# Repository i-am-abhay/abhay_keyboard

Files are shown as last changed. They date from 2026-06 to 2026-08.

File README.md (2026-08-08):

<div align="center">

<br><br><br>

Screenshot 2026-07-06 at 4 13 24 PM

<br><br><br><br><br><br>

<div align="left">

### About the Project

This project is a custom mechanical keyboard that I designed and built from scratch. It features a custom PCB, mechanical switches, RGB lighting, and a 128×32 OLED display. The keyboard runs custom firmware that handles the key matrix, USB input, OLED, and lighting.

I designed the PCB and case myself, then assembled the hardware and wrote the firmware to bring everything together. The goal was to make a keyboard that I could actually use every day while having complete control over both the hardware and software.

<br><br>

### Why I Built It

I wanted to see if I could build a full-size keyboard completely from scratch instead of buying one. I had already worked on smaller hardware projects, so this felt like a good way to take things further and build something I would actually use every day.

It also gave me a chance to work on things I hadn't done at this scale before, like designing a large PCB, routing a keyboard matrix, writing firmware, and making a case that all fit together properly. In the end, I wanted to turn something I use every day into a project I could design myself.

<br><br><br><br><br><br>

<div align="center">

### Sponsored By

<br><br>

Hack Club

<br><br><br><br>

pcbway-logo-png_seeklogo-615986

<br><br><br>

## PCBWay Sponsorship

<div align="left">
  
A massive thank you to **[PCBWay](https://www.pcbway.com/)** for sponsoring the manufacturing of the **Velune Keyboard PCB** and being a part of this journey!

When I first started this project, it was just an idea sitting in my head, the goal of designing my own mechanical keyboard completely from scratch. I wanted to experience every part of the process: drawing the schematic, designing the PCB, writing the firmware, creating the hardware, and eventually holding something I built myself.

After countless hours in KiCad, debugging, redesigning, and improving the design, the project reached a point where it was ready to leave my computer and become a real physical device. That is where PCBWay made a huge difference.

With PCBWay's support, my PCB design was able to become a real prototype that I can assemble, test, and continue improving. Having a professionally manufactured board for something I designed myself is an incredible milestone and a reminder of why I love building hardware.

This sponsorship is not just about getting PCBs manufactured. It is about making it possible for creators like me to learn through building and share that experience with others. I will be documenting the entire process, from PCB fabrication and assembly to testing the final keyboard, so others can follow along and hopefully be inspired to start their own projects.

### Learn More About PCBWay!

* 🌐 **PCB Manufacturing:** [PCBWay](https://www.pcbway.com/)
* 🛠️ **PCBWay Community:** [PCBWay Project Community](https://www.pcbway.com/project/)

I am genuinely thankful to the PCBWay team for supporting student creators and giving me the opportunity to turn an idea into a real piece of hardware. Your support helped make **abhay_keyboard** something more than just a design file. It became a project I can build, share, and continue improving.

Thank you, PCBWay, for believing in this project and helping me bring it to life.

</div>

<br><br><br><br>

<div align="center">

### Bill of Materials

<br>

<div align="center">

| Qty | Component | Cost |
| :-: | --- | --- |
| 78x | [SOD-123 Diodes](https://www.aliexpress.com/item/3256805388348871.html) | $1.53  |
| 79x | [1206 Capacitors (104K 50V)](https://www.aliexpress.com/item/3256807177349573.html) | $1.46  |
|  1x | [74AHCT125 Bus Buffer](https://www.aliexpress.com/item/3256807066238250.html) | $1.66  |
| 78x | [SK6812 MINI-E RGB LEDs](https://www.aliexpress.us/item/3256805007401420.html) | $6.48  |
|  1x | [SSD1306 128×32 OLED Display](https://www.aliexpress.com/item/2251832623890853.html) | $1.52  |
|  4x | [6mm M3 Machine Screws](https://www.aliexpress.com/item/2255800784679048.html) | $2.45  |
| 78x | [Mechanical Switches](https://www.aliexpress.com/item/3256808352947766.html) | $22.79 |
|  1x | [Raspberry Pi Pico RP2040](https://www.aliexpress.com/item/3256806652932348.html) | $7.28  |
|  1x | [Keycap Set](https://www.aliexpress.com/item/3256809986262551.html) | $15.51 |
|  1x | [Keyboard Stabilizer Set](https://www.aliexpress.com/item/3256801595153884.html) | $3.71  |
|  4x | [M2.5 Self-Tapping Screws](https://www.aliexpress.com/item/2255800784679048.html) | $2.61  |
|  4x | [M3 Heat-Set Inserts](https://www.aliexpress.com/item/3256808480358197.html) | $2.15  |
|  1x | [GPIO Header Set (Raspberry Pi Pico)](https://www.aliexpress.com/item/3256808268220851.html) | $2.19  |
|  1x | [Custom PCB  (**SPONSORED BY PCBWAY**)  ](https://www.pcbway.com/) | $0.00  |
|  1x | 3D Printed Case (Printing Legion) | $0.00  | 

<br>

**Parts Subtotal:** $76.48 

**Fees  |  Tax:** $6.34

**PCBWAY Shipping:** $60

**Grand Total:** $142.82

<br><br><br><br><br>

### PCB Schematic

<br>

Screenshot 2026-06-18 at 11 05 58 AM

<br><br>

### PCB Layout

<br>

<div align="center">

**Top Layer**

<br>

Screenshot 2026-06-18 at 5 12 39 PM

<br><br>

**Bottom Layer**

<br>

Screenshot 2026-06-18 at 5 12 57 PM

<br><br>

**3D View**

<br>

Screenshot 2026-06-18 at 5 15 27 PM

<br><br>

Screenshot 2026-06-18 at 5 15 45 PM

</div>

<br><br>

### Case Design

<br>

<div align="center">

**Top Case**

<br>

Screenshot 2026-06-18 at 5 12 09 PM

<br><br>

**Plate**

<br>

Screenshot 2026-06-18 at 5 11 52 PM

<br><br>

**Bottom Case**

<br>

Screenshot 2026-06-18 at 5 12 13 PM

</div>

<br><br>

### Final Assembly

<br>

<div align="center">

Screenshot 2026-06-18 at 5 18 41 PM

<br><br>

<div align="center">

*Designed and Built by Abhay P.*

</div>

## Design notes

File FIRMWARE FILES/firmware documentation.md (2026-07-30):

# Mechanical Keyboard Firmware Documentation

## Overview

This firmware runs my custom mechanical keyboard using a custom keyboard controller and CircuitPython firmware.

It handles:

- Full keyboard key input
- SSD1306 128×32 OLED display
- Per-key NeoPixel RGB LED lighting
- Full key matrix scanning
- USB keyboard input

Everything works together to handle typing input, visual feedback, and keyboard controls.

---

## Hardware

### Microcontroller

- Custom keyboard controller
- CircuitPython-compatible MCU

### Display

- SSD1306 OLED (128×32, I2C)
- Address: `0x3C`
- Framebuffer-based display driver

### Input

- Custom keyboard layout
- Full keyboard matrix
- Mechanical MX-style switches
- Diode-protected matrix

### Output

- Individual RGB LEDs assigned to each key
- Custom lighting effects and animations

---

## Pin Mapping

### Key Matrix

- Rows: Configured based on keyboard PCB layout
- Columns: Configured based on keyboard PCB layout
- Diode orientation: `COL2ROW`

### OLED (I2C)

- SDA: Configured GPIO pin
- SCL: Configured GPIO pin
- I2C Speed: 400 kHz

### RGB LEDs

- Data: Configured GPIO pin
- LED Count: Configured based on keyboard PCB

---

## Key System

Each key has:

- A physical switch position
- A keyboard keycode
- An RGB lighting position
- A matrix row and column location
- Optional custom behavior

### Current key actions

- Standard keyboard input
- Function keys
- Navigation keys
- Arrow keys
- Number pad support
- Modifier keys
- Media controls

---

## Key Press Behavior

When a key is pressed:

1. The matrix scanner detects the switch press.
2. The key debounce system confirms the input.
3. The keyboard sends the matching USB HID keycode.
4. The OLED updates with keyboard status.
5. The matching key LED animation starts.

When the key is released:

- The key state is cleared.
- The HID release signal is sent.
- The LED animation returns to the idle state.

---

## OLED System

The OLED uses a framebuffer-based driver.

### Features

- Text rendering
- Keyboard status display
- Layer information
- Animation support
- Direct I2C updates

---

## OLED Animation States

### Idle

- Shows the current time in `HH:MM`
- Shows keyboard status below
- Slightly moves the display content to prevent static appearance

### Key Press

- Displays the pressed key name.
- Shows keyboard activity feedback.
- Updates only when the screen state changes.

### Hold

- The key information remains displayed briefly.

### Fade Out

- The display clears with a smooth wipe animation.
- The OLED returns to the idle screen.

---

## LED System

The LED system controls all keyboard RGB LEDs.

### Behavior

- LEDs remain in the selected idle mode.
- Pressing a key starts a lighting animation.
- Each key can have its own RGB color.

### On Key Press

- The pressed key LED activates.
- Lighting effects spread across the keyboard.
- The selected key color is displayed.

### On Key Release

- LEDs return to the idle lighting state.
- Effects clear smoothly.

### How it Works

- The animation runs inside the keyboard main loop.
- It uses timed updates instead of blocking delays.
- Key scanning continues while effects are running.

---

## LED Animation Engine

The LEDs use a time-based animation system.

### Press Animation

- The pressed key lights first.
- The effect expands across nearby LEDs.
- Each LED uses its assigned color.

### Release Animation

- The effect fades away.
- LEDs return to their default state.

### Timing

- Animation frames update using timed intervals.
- No blocking delays are used.

---

## Keyboard Matrix

The keyboard uses a row and column scanning system.

### How it Works

- The firmware activates one row at a time.
- Column inputs are checked for switch presses.
- The pressed switch location is converted into a keycode.
- The HID report is sent over USB.

### Features

- Debouncing
- Multiple key support
- Modifier key handling
- Full keyboard compatibility

---

## USB HID System

The keyboard communicates as a standard USB keyboard device.

### Features

- Plug-and-play support
- Standard keyboard shortcuts
- Modifier support
- Media key support

---

## Performance

### OLED

- The display only updates when required.
- Animations control when each frame is drawn.

### LEDs

- LED animations run inside the keyboard scan loop.
- They do not interrupt typing.
- Updates happen asynchronously.

### Input

- Matrix scanning runs continuously.
- Key presses are detected with low latency.
- Multiple keys can be pressed simultaneously.

---

## System Flow

1. A key is pressed.
2. The matrix scanner detects the switch.
3. The firmware processes the key event.
4. The USB HID report is sent.
5. The OLED shows keyboard feedback.
6. The RGB LED animation starts.
7. The keyboard returns to the idle state.

---

## Summary

This firmware brings the entire keyboard system together.

It includes:

- Full keyboard support
- Custom matrix scanning
- OLED visual feedback
- RGB lighting effects
- USB HID keyboard output

Everything runs together so the input system, display, lighting, and keyboard controls stay synchronized.

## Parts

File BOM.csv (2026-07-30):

Designator | Qty | Part Number | Package
C79,C61,C15,C1,C16,C76,C30,C54,C37,C67,C24,C66,C69,C27,C65,C11,C78,C68,C64,C13,C14,C62,C47,C71,C35,C4,C74,C5,C60,C9,C21,C45,C19,C25,C59,C17,C28,C8,C73,C56,C34,C50,C75,C22,C2,C29,C55,C46,C52,C20,C39,C44,C6,C33,C12,C7,C58,C38,C32,C36,C53,C43,C49,C42,C51,C70,C3,C77,C18,C41,C26,C57,C23,C40,C63,C48,C10,C72,C31 | 79 | 100nF | C_1206_3216Metric_Pad1.33x1.80mm_HandSolder
R1 | 1 | 330R | R_0805_2012Metric_Pad1.20x1.40mm_HandSolder
U2 | 1 | 74AHCT125 | SOIC-14_3.9x8.7mm_P1.27mm
D73,D25,D44,D31,D72,D66,D29,D37,D57,D63,D48,D67,D27,D70,D1,D49,D41,D64,D52,D74,D38,D23,D76,D60,D33,D16,D77,D46,D61,D47,D43,D15,D11,D34,D65,D51,D62,D14,D59,D56,D19,D40,D3,D32,D69,D10,D39,D13,D53,D6,D58,D45,D7,D54,D42,D36,D24,D35,D9,D22,D17,D8,D21,D18,D26,D28,D30,D75,D78,D55,D4,D50,D12,D68,D71,D20,D2,D5 | 78 | D | D_SOD-123
U1 | 1 | ER_OLEDM0.91_1x-I2C | ER_OLEDM0.91_1x-I2C
LED18,LED23,LED22,LED29,LED52,LED46,LED74,LED17,LED43,LED21,LED3,LED1,LED28,LED63,LED51,LED53,LED20,LED78,LED38,LED7,LED54,LED62,LED12,LED45,LED37,LED70,LED48,LED64,LED16,LED11,LED68,LED26,LED72,LED66,LED8,LED41,LED65,LED59,LED58,LED47,LED15,LED14,LED40,LED75,LED27,LED10,LED56,LED39,LED55,LED50,LED57,LED31,LED42,LED76,LED24,LED34,LED35,LED19,LED71,LED61,LED5,LED9,LED77,LED60,LED67,LED73,LED36,LED13,LED32,LED6,LED69,LED4,LED30,LED49,LED44,LED25,LED33,LED2 | 78 | MX_SK6812MINI-E | LED_MX_6028R
H1,H3,H2,H4 | 4 | MountingHole | MountingHole_3.2mm_M3
A1 | 1 | SC0918 | RaspberryPi_Pico_Common_THT
SW16,SW49,SW38,SW76,SW10,SW32,SW45,SW21,SW18,SW65,SW14,SW30,SW31,SW17,SW24,SW9,SW58,SW56,SW37,SW25,SW6,SW8,SW22,SW62,SW57,SW34,SW1,SW36,SW64,SW44,SW26,SW59,SW4,SW47,SW43,SW52,SW7,SW53,SW19,SW46,SW20,SW12,SW13,SW15,SW63,SW3,SW29,SW60,SW50,SW78,SW39,SW33,SW2,SW77,SW5,SW40,SW61,SW35,SW11,SW48,SW51,SW23 | 62 | SW_Push | SW_Cherry_MX_1.00u_PCB
SW69,SW75,SW67,SW72,SW70,SW73,SW74,SW68 | 8 | SW_Push | SW_Cherry_MX_1.25u_PCB
SW41,SW28 | 2 | SW_Push | SW_Cherry_MX_1.50u_PCB
SW42 | 1 | SW_Push | SW_Cherry_MX_1.75u_PCB
SW27 | 1 | SW_Push | SW_Cherry_MX_2.00u_PCB
SW54,SW55 | 2 | SW_Push | SW_Cherry_MX_2.25u_PCB
SW66 | 1 | SW_Push | SW_Cherry_MX_2.75u_PCB
SW71 | 1 | SW_Push | SW_Cherry_MX_6.25u_PCB

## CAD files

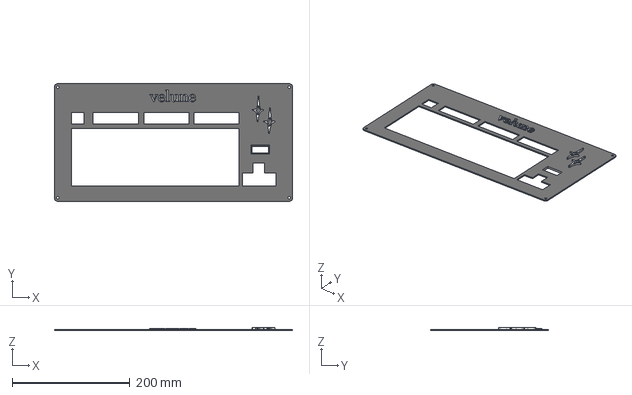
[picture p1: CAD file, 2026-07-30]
CAD FILES/KEYBOARD TOP CASE.step
405.0 x 200.0 x 5.00 mm

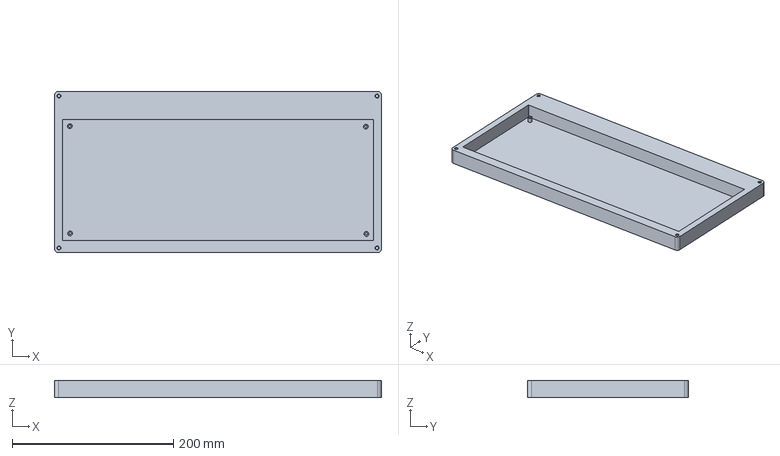
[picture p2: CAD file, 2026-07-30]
CAD FILES/KEYBOARD BOTTOM CASE.step
405.1 x 200.0 x 21.5 mm

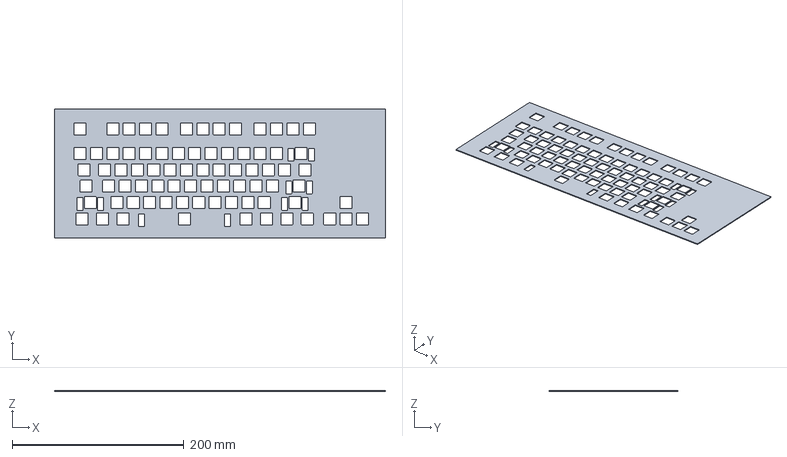
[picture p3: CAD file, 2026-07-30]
CAD FILES/PRODUCTION FOLDER/KEYBOARD PLATE.step
385.1 x 150.0 x 1.00 mm

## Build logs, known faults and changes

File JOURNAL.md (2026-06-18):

# 1. Keyboard Layout Planning

> ⏱️ **Time Logged:** 2 Hours

Before starting the electrical design, I spent time deciding on the overall layout of the keyboard. I chose a 75% layout because it balances functionality and desk space well. One challenge was fitting all 75 keys while maintaining comfortable spacing and room for the OLED display. I experimented with several arrangements before settling on the final design. This planning stage helped prevent larger issues later in the project and gave me a clearer idea of how all the components would fit together.

---

# 2. Schematic Design

> ⏱️ **Time Logged:** 4 Hours

I worked on creating the schematic for the keyboard. Compared to smaller projects I had done previously, this design was significantly more complicated because it included 75 switches, a Raspberry Pi Pico, an OLED display, and RGB underglow LEDs.

One challenge I encountered was organizing the keyboard matrix and ensuring every switch was connected correctly. During the design process I ran into several ERC errors caused by missing connections and incorrect net assignments. Rather than trying random fixes, I systematically reviewed each section of the schematic and traced every issue back to its source. After multiple revisions, I was able to eliminate all errors and complete a schematic that was both functional and organized.

---

# 3. PCB Layout & Routing

> ⏱️ **Time Logged:** 6 Hours

I worked on laying out and routing the PCB for the keyboard. This was by far the most time-consuming portion of the project.

With 75 switches, RGB LEDs, the OLED display, and supporting circuitry, routing quickly became challenging due to the large number of connections and limited space available. My initial placement resulted in several congested areas where routing became difficult. To solve this, I repositioned components multiple times and rerouted large portions of the board to improve trace organization.

I also had to carefully consider mounting hole placement and mechanical clearances to ensure traces would not be damaged during assembly. This stage taught me the importance of balancing electrical requirements with mechanical constraints. Overall, I am very happy with how compact and organized the final PCB turned out.

---

# 4. Plate Design

> ⏱️ **Time Logged:** 2 Hours

I designed the keyboard plate that supports all 75 switches. While it seemed straightforward at first, ensuring that every switch cutout was aligned correctly required careful attention to detail.

I spent time verifying measurements against both the PCB and key layout to ensure proper fitment. Since even small alignment errors can affect the assembly process, I double-checked all dimensions before finalizing the design.

---

# 5. Top Case Design

> ⏱️ **Time Logged:** 2 Hours

I created the top case for the keyboard. The primary challenge was integrating the switch openings, OLED display opening, and overall aesthetics while maintaining compatibility with the plate and PCB.

I made several adjustments to dimensions and clearances to ensure components would fit comfortably without interfering with one another. The final design provides support while maintaining a clean appearance.

---

# 6. Bottom Case Design

> ⏱️ **Time Logged:** 2 Hours

I created the bottom case that houses the PCB and internal electronics. Although the design itself was relatively simple, determining the correct dimensions required careful measurement.

I had to account for the thickness of the PCB, standoffs, mounting hardware, and tolerances associated with 3D printing. To reduce the risk of assembly issues, I added additional clearance in several locations where the fit would otherwise have been too tight.

---

# 7. Assembly Creation & Verification

> ⏱️ **Time Logged:** 1.5 Hours

I created a complete assembly model of the keyboard to verify that all components fit together correctly.

During this stage I discovered a few minor alignment issues that were not obvious when viewing individual parts. Being able to identify and correct these problems before manufacturing saved both time and potential cost. The assembly also allowed me to visualize the finished product and confirm that all dimensions were correct.

---

# 8. Firmware Development

> ⏱️ **Time Logged:** 2.5 Hours

I developed the firmware for the keyboard. Since I already had experience with Python, learning the basic structure of the firmware was not difficult. However, configuring the keyboard matrix, OLED display functionality, and RGB lighting required learning several new concepts.

I spent time reading documentation and experimenting with test configurations before implementing the final design. While there was a learning curve at first, I gained a much better understanding of how firmware interacts with hardware systems.

---

# 9. Parts Sourcing

> ⏱️ **Time Logged:** 2 Hours

I sourced all of the components required for the keyboard, including switches, keycaps, LEDs, the Raspberry Pi Pico, display, and assembly hardware.

I originally expected this process to be quick, but I quickly discovered that balancing cost, quality, and availability was more difficult than anticipated. Several components were either out of stock or significantly more expensive than expected. After comparing multiple suppliers and alternatives, I finalized a bill of materials that met both performance and budget requirements.

---

# 10. GitHub Repository & Documentation

> ⏱️ **Time Logged:** 1 Hour

I organized all project files and uploaded them to my GitHub repository. I also created documentation describing the project, design process, and manufacturing files.

Although documentation was one of the final steps, I believe it is an important part of any engineering project because it allows others to understand, reproduce, and improve upon the design in the future.

---

# Total Project Statistics

| Category | Time Logged |
| --- | ---: |
| Keyboard Layout Planning | 2 hrs |
| Schematic Design | 4 hrs |
| PCB Layout & Routing | 6 hrs |
| Plate Design | 2 hrs |
| Top Case Design | 2 hrs |
| Bottom Case Design | 2 hrs |
| Assembly Creation & Verification | 1.5 hrs |
| Firmware Development | 2.5 hrs |
| Parts Sourcing | 2 hrs |
| GitHub & Documentation | 1 hr |
| **Total Time** |  **25 hrs** |

---

# Reflection

I am immensely grateful for the opportunity to design and develop a custom keyboard from the ground up. I started this project because I wanted to create something that combined electrical engineering, mechanical design, and software development into a single product that I could personally use.

One of the biggest lessons I learned was that engineering is an iterative process. Whether I was fixing ERC errors, rerouting traces on the PCB, adjusting mechanical tolerances, or learning how to configure firmware features, very few parts of the project worked perfectly on the first attempt. Each challenge required research, experimentation, and multiple revisions before reaching a satisfactory solution.

Throughout the project I became more comfortable using professional design tools and working through technical problems independently. I also gained a deeper understanding of how electrical, mechanical, and software systems interact within a complete product. Most importantly, I was able to transform an initial idea into a fully designed keyboard that I am genuinely proud of. The experience and skills gained throughout this project will be valuable in future engineering projects and have strengthened my interest in hardware design.

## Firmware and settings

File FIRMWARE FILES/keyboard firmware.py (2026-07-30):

# code.py
# ANSI 104 Keyboard Placeholder
# Matrix + OLED + RGB LEDs

import time
import board
import busio
import displayio
import terminalio

from digitalio import DigitalInOut, Direction, Pull
import neopixel

import adafruit_displayio_ssd1306
from adafruit_display_text import label


# ==================================================
# OLED DISPLAY
# ==================================================

displayio.release_displays()

# Change pins if needed
i2c = busio.I2C(
    board.D5,   # SCL
    board.D4,   # SDA
    frequency=400000
)

display_bus = displayio.I2CDisplay(
    i2c,
    device_address=0x3C
)

display = adafruit_displayio_ssd1306.SSD1306(
    display_bus,
    width=128,
    height=32
)

screen = displayio.Group()

text = label.Label(
    terminalio.FONT,
    text="ANSI 104 Keyboard",
    x=0,
    y=8
)

screen.append(text)

display.root_group = screen


# ==================================================
# RGB LEDS
# ==================================================

# Change pin and count
LED_PIN = board.D10
LED_COUNT = 104

pixels = neopixel.NeoPixel(
    LED_PIN,
    LED_COUNT,
    brightness=0.2,
    auto_write=True
)

# Startup placeholder lighting
for i in range(LED_COUNT):
    pixels[i] = (20, 20, 20)

time.sleep(1)

pixels.fill((0, 0, 0))


# ==================================================
# ANSI 104 KEYMAP PLACEHOLDER
# ==================================================

KEYMAP = [

    # Function row
    [
        "ESC",
        "F1","F2","F3","F4",
        "F5","F6","F7","F8",
        "F9","F10","F11","F12"
    ],

    # Number row
    [
        "`","1","2","3","4",
        "5","6","7","8",
        "9","0","-","=",
        "BACKSPACE"
    ],

    # Q row
    [
        "TAB",
        "Q","W","E","R","T",
        "Y","U","I","O","P",
        "[","]","\\"
    ],

    # Home row
    [
        "CAPS",
        "A","S","D","F","G",
        "H","J","K","L",
        ";","'",
        "ENTER"
    ],

    # Bottom row
    [
        "SHIFT_L",
        "Z","X","C","V","B",
        "N","M",
        ",",".","/",
        "SHIFT_R"
    ],

    # Space row
    [
        "CTRL_L",
        "WIN_L",
        "ALT_L",
        "SPACE",
        "ALT_R",
        "FN",
        "CTRL_R"
    ],

    # Navigation
    [
        "INSERT",
        "HOME",
        "PAGE_UP",
        "DELETE",
        "END",
        "PAGE_DOWN"
    ],

    # Arrows
    [
        "UP",
        "LEFT",
        "DOWN",
        "RIGHT"
    ],

    # Numpad
    [
        "NUM_LOCK",
        "NUM/",
        "NUM*",
        "NUM-",
        "NUM7",
        "NUM8",
        "NUM9",
        "NUM+",
        "NUM4",
        "NUM5",
        "NUM6",
        "NUM1",
        "NUM2",
        "NUM3",
        "NUM_ENTER",
        "NUM0",
        "NUM."
    ]
]


# ==================================================
# MATRIX PLACEHOLDER
# ==================================================

ROWS = []
COLS = []


def scan_keyboard():
    """
    Add matrix scanning here:
    - set row pins
    - read columns
    - send HID reports
    """
    pass


# ==================================================
# MAIN LOOP
# ==================================================

while True:

    scan_keyboard()

    # OLED heartbeat placeholder
    text.text = "ANSI 104 Keyboard"

    time.sleep(0.01)

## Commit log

2026-07-30 Rename Wireless Keyboard.kicad_pcb to PCB FILES/Wireless Keyboard.kicad_pcb
    [Wireless Keyboard.kicad_pcb]
2026-07-30 Rename Wireless Keyboard.kicad_pro to PCB FILES/Wireless Keyboard.kicad_pro
2026-07-30 Rename Wireless Keyboard.kicad_sch to PCB FILES/Wireless Keyboard.kicad_sch
    [Wireless Keyboard.kicad_sch]
2026-07-30 Rename Keyboard.kicad_pcb to PCB FILES/Keyboard.kicad_pcb
    [Keyboard.kicad_pcb]
2026-07-30 Rename Keyboard.kicad_pro to PCB FILES/Keyboard.kicad_pro
2026-07-30 Rename Keyboard.kicad_sch to PCB FILES/Keyboard.kicad_sch
    [Keyboard.kicad_sch]
2026-07-30 Rename KEYBOARD BOTTOM CASE.step to CAD FILES/KEYBOARD BOTTOM CASE.step
    [KEYBOARD BOTTOM CASE.step]
2026-07-30 Rename KEYBOARD PLATE.step to CAD FILES/KEYBOARD PLATE.step
    [KEYBOARD PLATE.step]
2026-07-30 Rename KEYBOARD TOP CASE.step to CAD FILES/KEYBOARD TOP CASE.step
    [KEYBOARD TOP CASE.step]
2026-08-05 Update pricing for Custom PCB entry in README
    Removed pricing information for Custom PCB.
2026-08-05 Update Custom PCB description in README
    Removed sponsorship mention for Custom PCB.
2026-08-06 Update section header for PCBWay information
2026-08-06 Revise PCBWay sponsorship details in README
    Updated sponsorship acknowledgment from 'abhay_keyboard PCB' to 'Velune Keyboard'.
2026-09-06 Rename CAD FILES/KEYBOARD BOTTOM CASE.step to CAD FILES/PRODUCTION FOLDER/KEYBOARD BOTTOM CASE.step
    [KEYBOARD BOTTOM CASE.step]
2026-09-06 Rename CAD FILES/KEYBOARD PLATE.step to CAD FILES/PRODUCTION FOLDER/KEYBOARD PLATE.step
    [KEYBOARD PLATE.step]
2026-09-06 Rename CAD FILES/KEYBOARD TOP CASE.step to CAD FILES/PRODUCTION FOLDER/KEYBOARD TOP CASE.step
    [KEYBOARD TOP CASE.step]
2026-09-06 Rename CAD FILES/PRODUCTION FOLDER/KEYBOARD BOTTOM CASE.step to CAD FILES/KEYBOARD BOTTOM CASE.step
    [KEYBOARD BOTTOM CASE.step]
2026-09-06 Rename CAD FILES/PRODUCTION FOLDER/KEYBOARD TOP CASE.step to CAD FILES/KEYBOARD TOP CASE.step
    [KEYBOARD TOP CASE.step]
